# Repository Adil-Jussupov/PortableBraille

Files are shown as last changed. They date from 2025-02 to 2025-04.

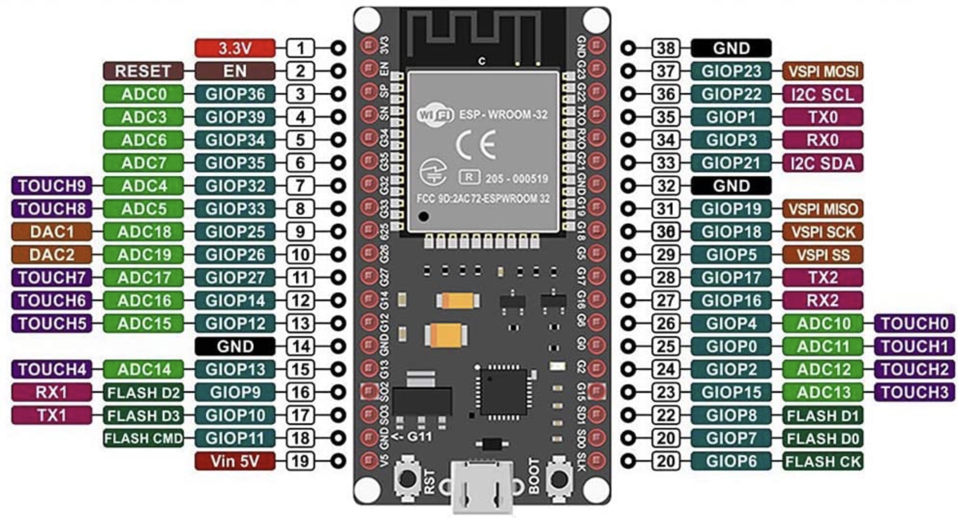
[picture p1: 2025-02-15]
DataSheets/ESP32-Pinouts.jpg

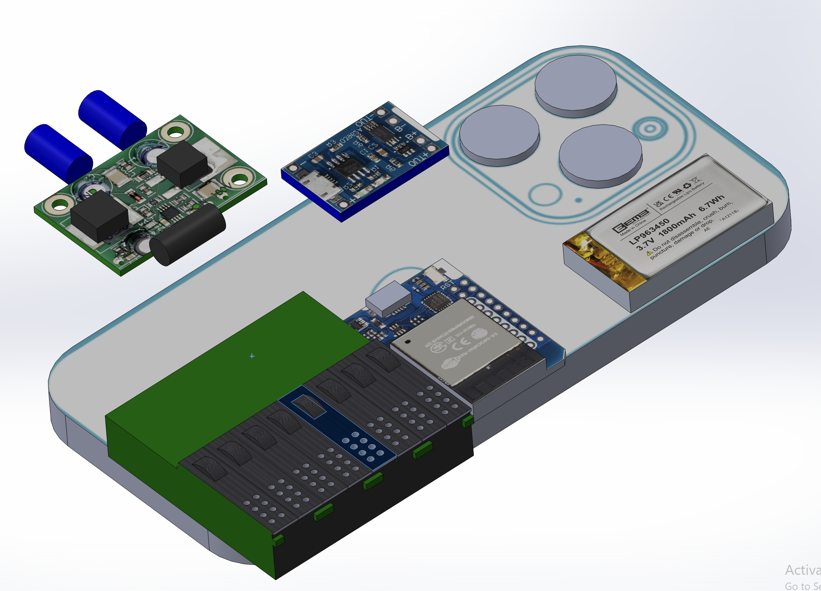
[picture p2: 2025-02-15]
Pitch_Deck/Components.png

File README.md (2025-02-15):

# PortableBraille
Educational device that encourages young visually impaired people to learn and practice Braille in order to increase chances for future employment and expand general literacy level of the community.

# Plan for designing and making the device:

1. Collected data sheets of potential components
2. Draw a schematics of the device
3. Put all components on a breadboard and run the test firmware
4. Choose electroni components to use
5. Draw several sketches of the device itself, with Phone, in hands
6. Make 3d-models of standard components
7. Asseble all standard components in general assembly
8. Model a boundry box of the device according to sketches
9. Refine the 3d-model of the device
10. Create a 3d-model of an enclosure of the divice in accordance with its 3d-Model
11. Convert parts to STL or 3dmf format
12. Slice parts and send to 3d-print
13. Put all the components inside the enclosure and if somethind doesn't fit, andjust the model and reprint.
14. Improve firmware
15. Test with user.

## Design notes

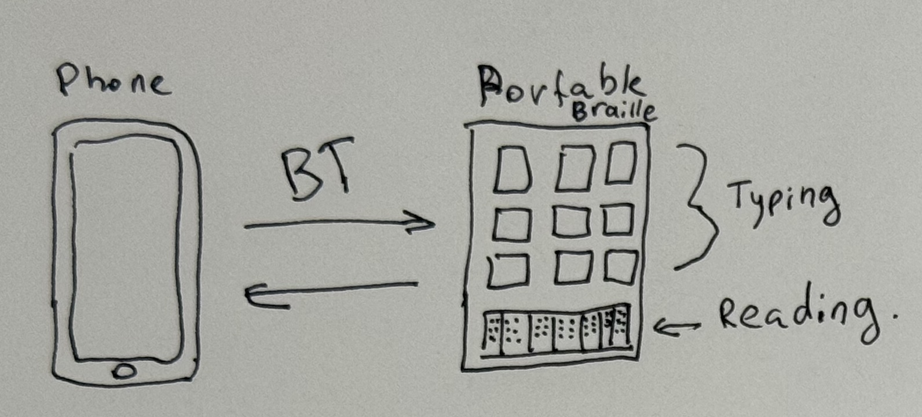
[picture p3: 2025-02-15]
Pitch_Deck/Main_schematics.jpg

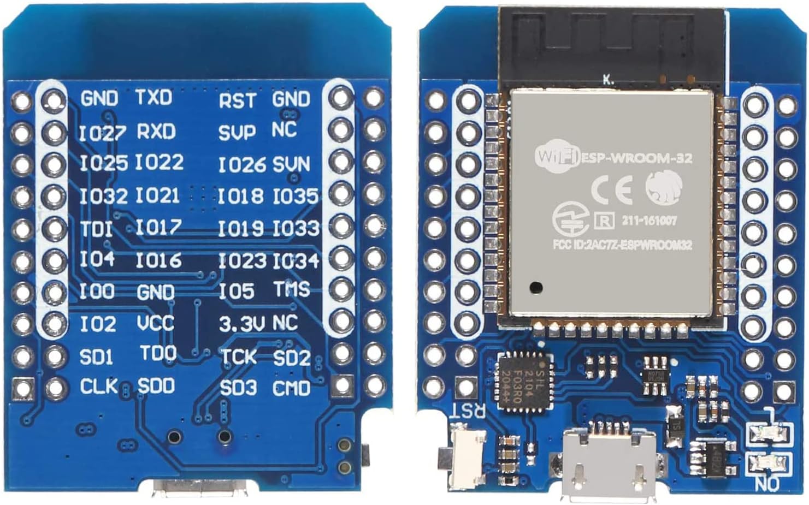
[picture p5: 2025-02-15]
DataSheets/HiLetgo_Mini_ESP-32_top_bottom.jpg

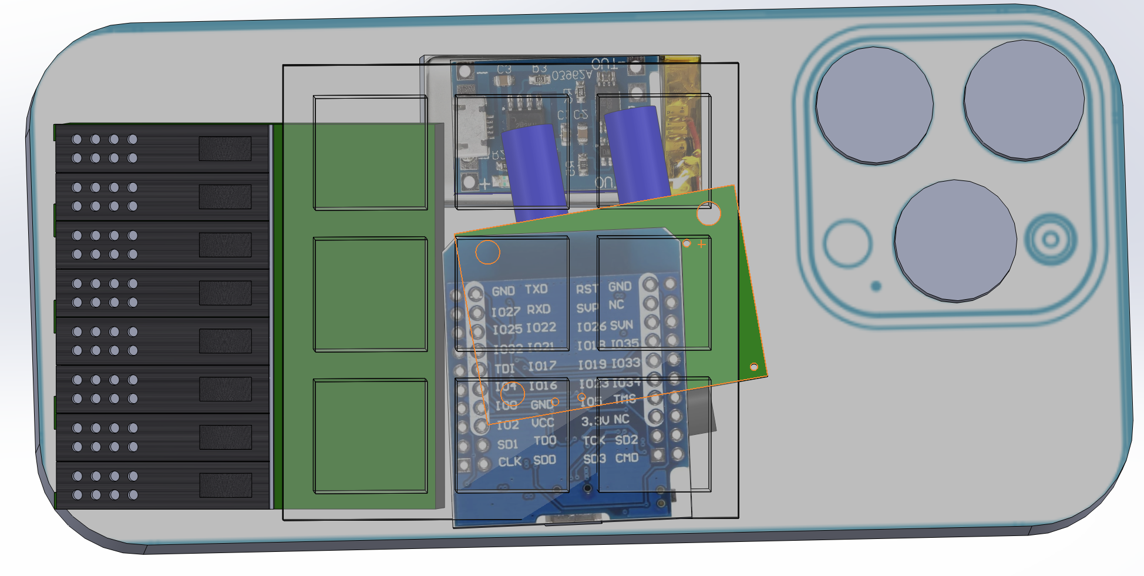
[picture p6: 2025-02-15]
Pitch_Deck/Final_arrangement.png

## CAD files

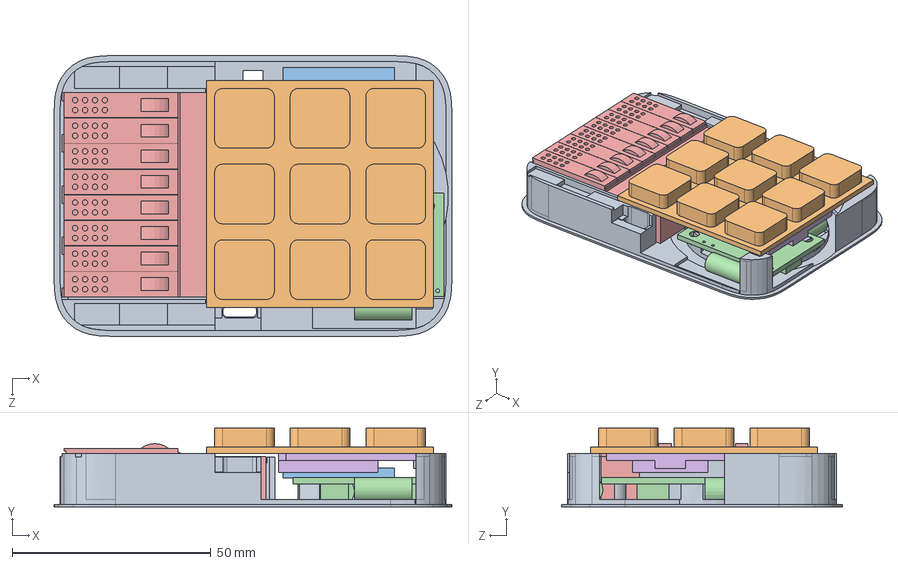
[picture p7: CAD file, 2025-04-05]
Enclosure/PB_assembly.SLDASM
100.0 x 19.8 x 70.6 mm
Mini-ESP32
Braille_flat_8
DC-DC_Metec
TP4056
Keypad
PB_Enclocure_Bottom

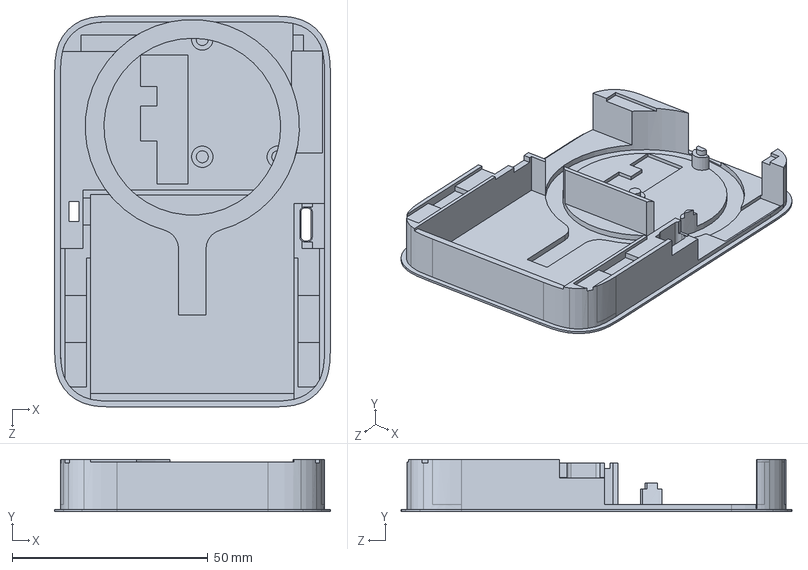
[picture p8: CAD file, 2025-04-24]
Enclosure/PB_Enclocure_Bottom.SLDPRT
70.6 x 13.4 x 100.0 mm

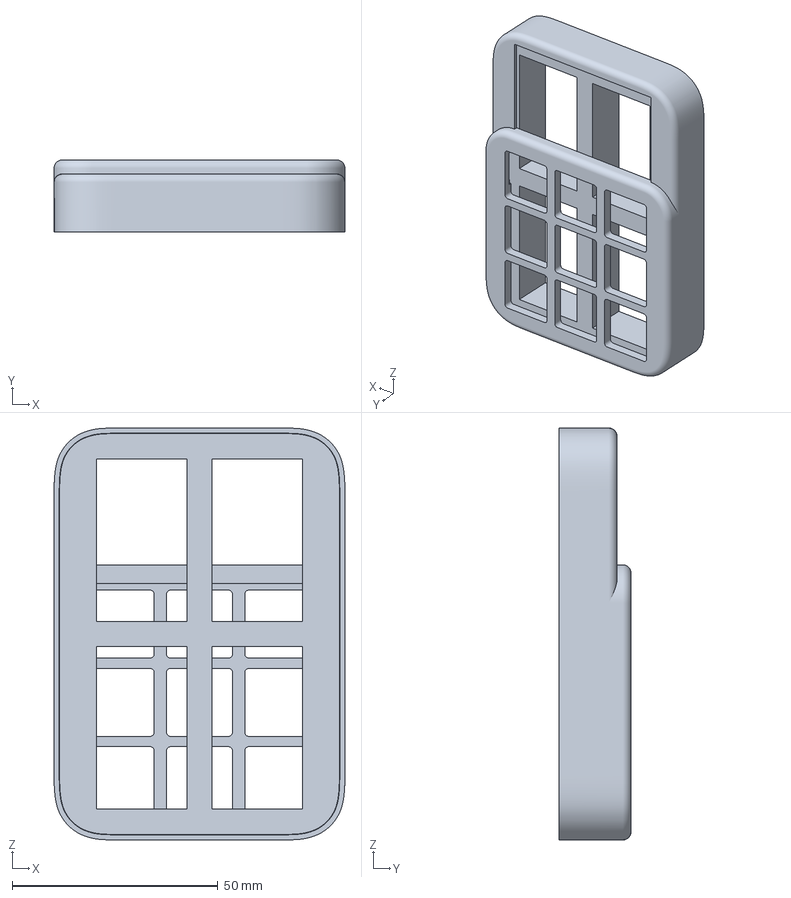
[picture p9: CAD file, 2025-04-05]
Enclosure/STL/PB_Enc_top.3MF
70.6 x 17.5 x 100.0 mm

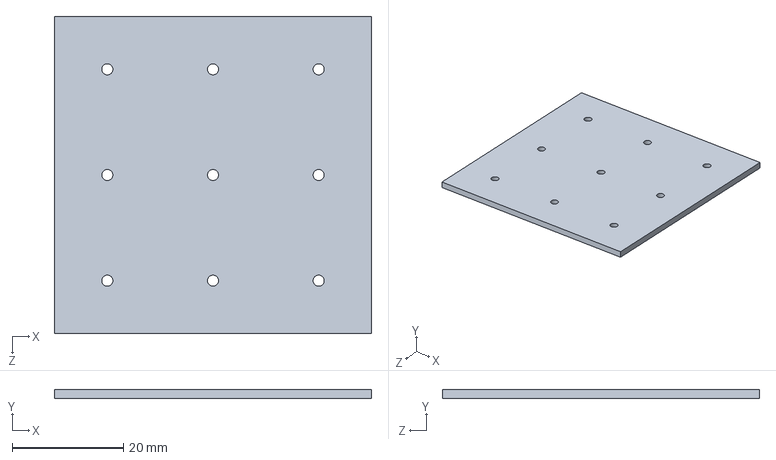
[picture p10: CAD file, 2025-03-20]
Enclosure/Part1.SLDPRT
57.0 x 1.60 x 57.0 mm

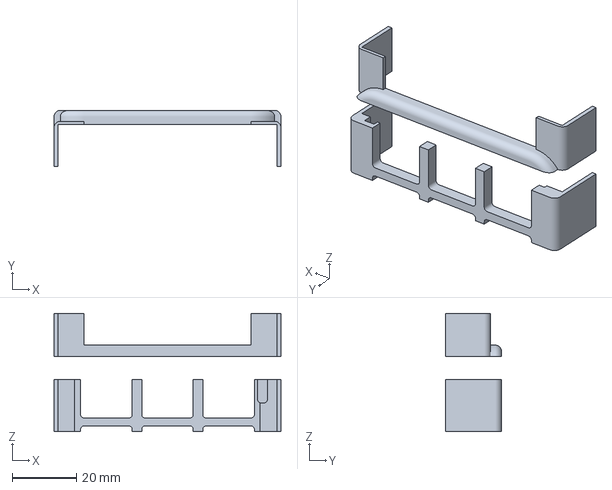
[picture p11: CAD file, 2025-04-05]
Enclosure/STL/PB_top_test.3MF
70.6 x 17.5 x 36.7 mm

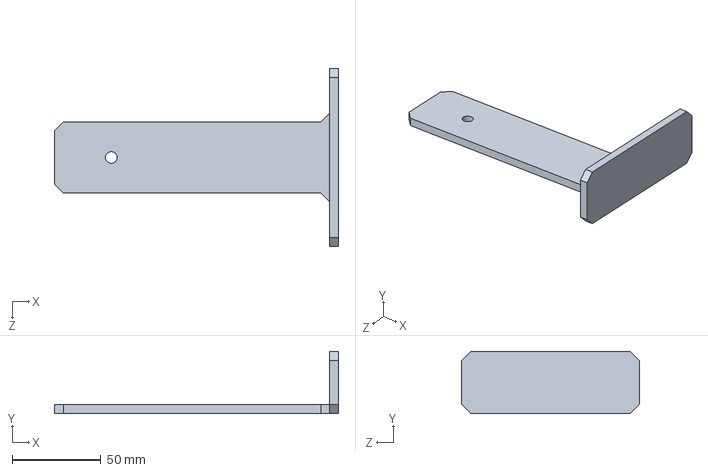
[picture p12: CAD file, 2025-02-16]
Enclosure/Camera_holder.SLDPRT
160.0 x 35.0 x 100.0 mm

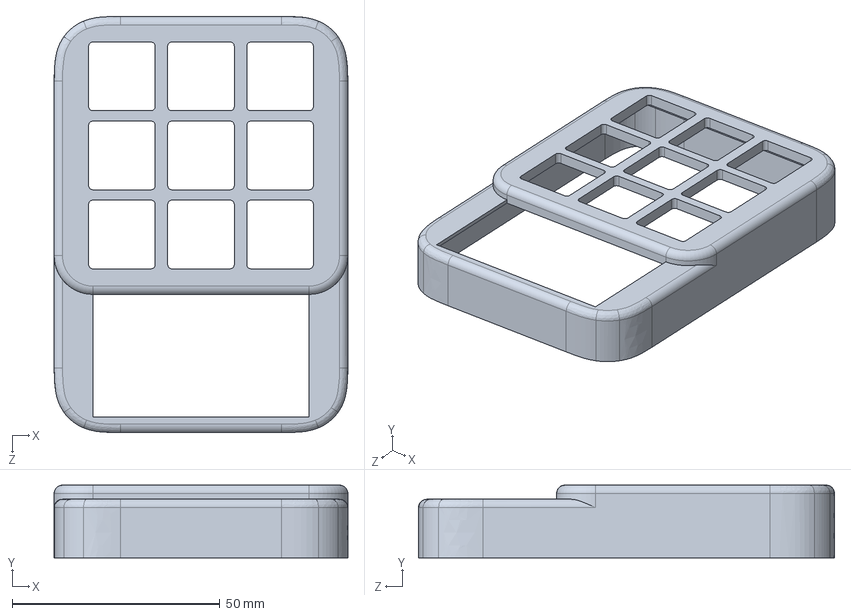
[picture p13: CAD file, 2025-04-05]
Enclosure/STL/PB_Enclocure_top.STEP
70.6 x 17.5 x 100.0 mm

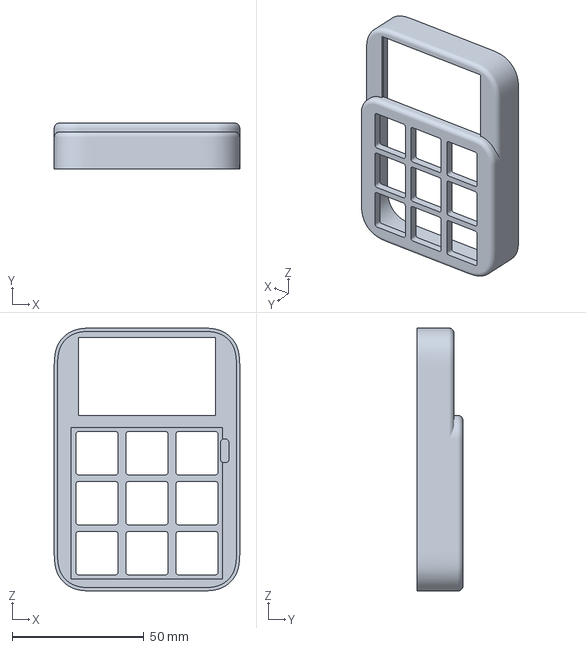
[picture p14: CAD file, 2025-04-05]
Enclosure/STL/PB_Bottom.3MF
70.6 x 17.5 x 100.0 mm

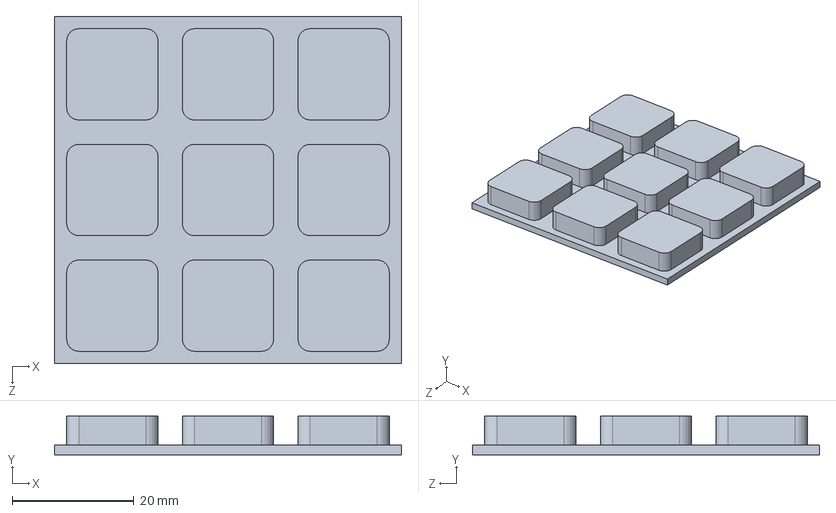
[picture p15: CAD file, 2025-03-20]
Enclosure/Standard_Parts/Keypad.SLDPRT
57.0 x 6.40 x 57.0 mm

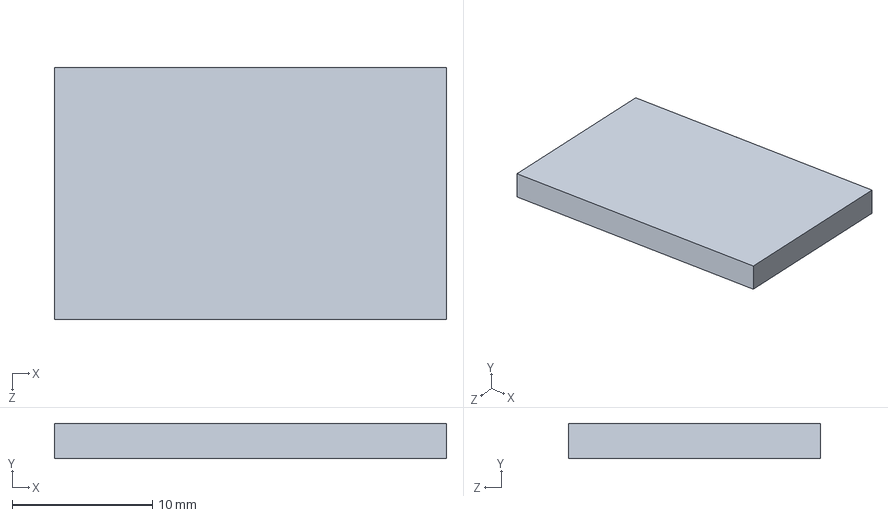
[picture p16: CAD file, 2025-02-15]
Enclosure/Standard_Parts/TP4056.SLDPRT
28.0 x 2.50 x 18.0 mm

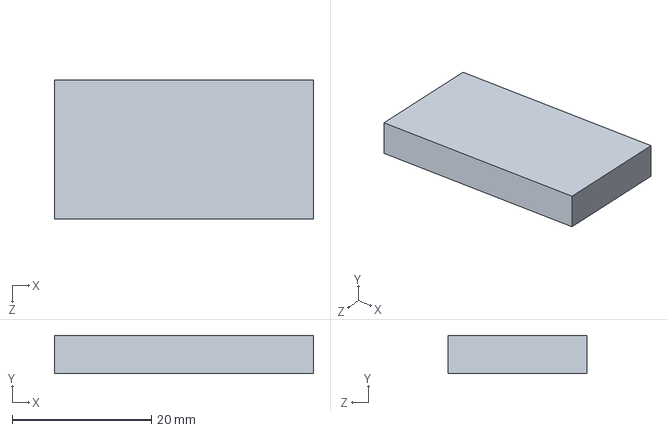
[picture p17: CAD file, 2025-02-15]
Enclosure/Standard_Parts/LiPo20x37.SLDPRT
37.2 x 5.50 x 20.0 mm

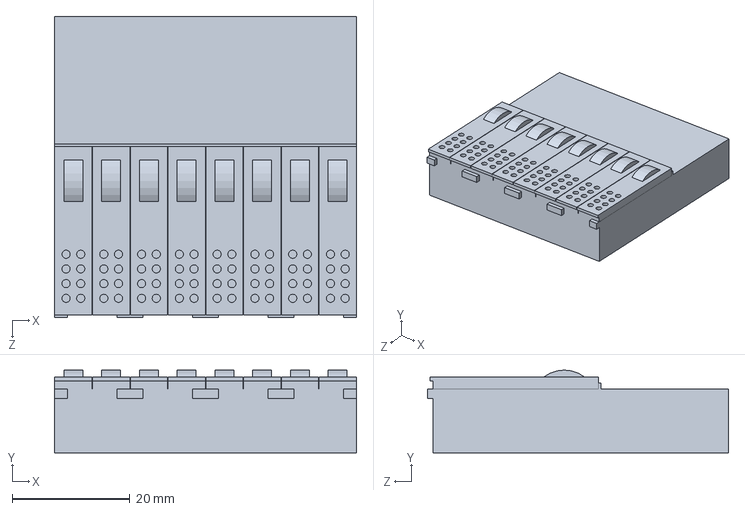
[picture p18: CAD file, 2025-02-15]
Enclosure/Standard_Parts/Braille_flat_8.SLDPRT
51.4 x 14.1 x 51.3 mm

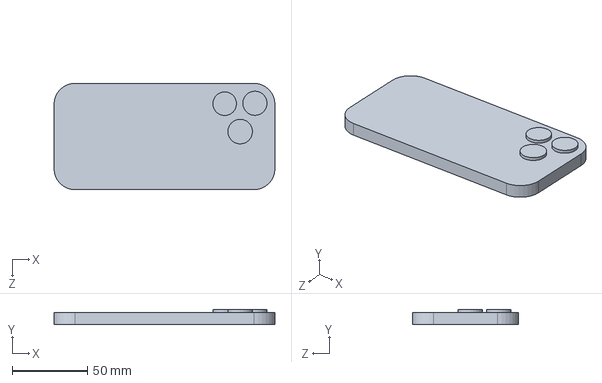
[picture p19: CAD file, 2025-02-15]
Enclosure/Standard_Parts/iPhone15Pro.SLDPRT
146.6 x 10.2 x 70.6 mm

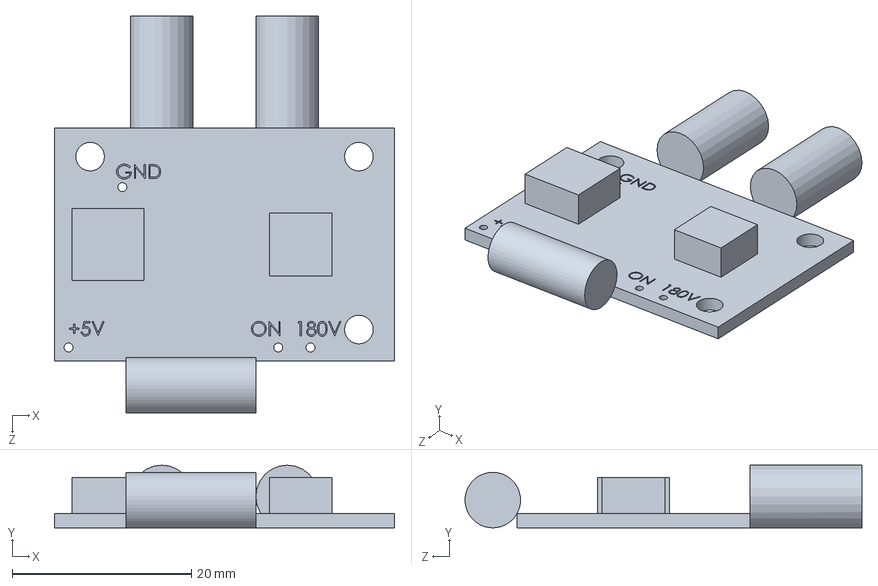
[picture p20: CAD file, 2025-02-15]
Enclosure/Standard_Parts/DC-DC_Metec.SLDPRT
38.0 x 7.00 x 44.3 mm

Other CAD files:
Enclosure/STL/PB_Enc_Bot.3MF
Enclosure/Standard_Parts/ESP32-WROOM.SLDPRT
Enclosure/Standard_Parts/Mini-ESP32.SLDPRT
Enclosure/PB_Enclocure_top.SLDPRT
Enclosure/STL/Camera_holder.3MF
Enclosure/STL/PB_Enclocure_Bottom.STL
Enclosure/STL/PB_Enclocure_top.3MF

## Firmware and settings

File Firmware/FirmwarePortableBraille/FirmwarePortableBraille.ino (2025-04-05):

// TreeHacks 2025
// PortableBraille by Adil Jussupov
// Jussupov@stanford.edu

// Define constants for pins for buttons
// mini-ESP32
#define BTN1 21
#define BTN2 19
#define BTN3 18

#define BTN4 16
#define BTN5 5
#define BTN6 23

#define BTN7 33
#define BTN8 17
#define BTN9 26

#define POWERON 4

int datainPin = 32;  //to cell, 'in' from perspective braille cell
int strobePin = 25;  //to cell
int clockPin = 27;   //to cell

unsigned int i;
float delaytime = 0.25;

#include <BleKeyboard.h>.  // library to conver device to BLE HID (Bluetooth keyboard)
#include "brailleconst.h"  // arrays for conversion to Braille

BleKeyboard bleKeyboard;

// variables for multiple buttons pressing
bool hasKeyPressed = false;      // variable for tracking and releasing pressed key
long keyPreviusTime = millis();  // temp var for time
long keyReleasTime = 10;         // time have key pressed

int number = 0;
long previousTime = millis();
long updatePeriod = 50;


#include "GyverButton.h"  // buttons library
GButton butt1(BTN1);
GButton butt2(BTN2);
GButton butt3(BTN3);
GButton butt4(BTN4);
GButton butt5(BTN5);
GButton butt6(BTN6);
GButton buttSpace(BTN7);
GButton buttBSpace(BTN8);
GButton buttEnter(BTN9);

void setup() {

  //pinMode(powerPin, OUTPUT);
  // pinMode(powerPin, OUTPUT);
  // digitalWrite(powerPin, LOW);  // controlpin for DCDC converter (low is on)
  pinMode(datainPin, OUTPUT);
  pinMode(strobePin, OUTPUT);
  pinMode(clockPin, OUTPUT);
  delay(50);

  Serial.begin(115200);
  Serial.println("Starting BLE connection");
  bleKeyboard.begin();

  pinMode(POWERON, OUTPUT);                     // pin for turning DC-DC converter on
  digitalWrite(POWERON, LOW);                   // turn off DC-DC
  // while (!bleKeyboard.isConnected()) {}  // wait untill bluetooth connected
  // Serial.println("BLE Connected");
}

void loop() {

  // tick every cycle to check buttons
  butt1.tick();
  butt2.tick();
  butt3.tick();
  butt4.tick();
  butt5.tick();
  butt6.tick();
  buttSpace.tick();
  buttBSpace.tick();
  buttEnter.tick();

  // check if button was pressed
  if (butt1.isClick()) {
    if (!number) previousTime = millis();
    if (!(number & (1 << 0))) {
      number += 1 << 0;
    }

    digitalWrite(strobePin, LOW);  // low for setting data, high for using data
    for (i = 0; i < 64; i++)       //we have five cells of eight pins, so amount is 40
    {
      digitalWrite(clockPin, LOW);  // set clock low before sending value for 1 braille pin
      if ((i % 2) == 0) {
        digitalWrite(datainPin, LOW);
      } else {
        digitalWrite(datainPin, HIGH);
      }
      delay(delaytime);              //delay must be very short
      digitalWrite(clockPin, HIGH);  //set clock low
      delay(delaytime);
    }
    digitalWrite(strobePin, HIGH);  //pattern is set and
  }
  if (butt2.isClick()) {
    if (!number) previousTime = millis();
    if (!(number & (1 << 1))) {
      number += 1 << 1;
    }

    digitalWrite(strobePin, LOW);  // low for setting, high for using data
    for (i = 0; i < 64; i++) {
      digitalWrite(clockPin, LOW);  // set clock low
      if ((i % 2) == 0)             //odd pins go down, even ones go up
      {
        digitalWrite(datainPin, HIGH);
      } else {
        digitalWrite(datainPin, LOW);
      }
      delay(delaytime);
      digitalWrite(clockPin, HIGH);
      delay(delaytime);
    }
    digitalWrite(strobePin, HIGH);
  }

  if (butt3.isClick()) {
    if (!number) previousTime = millis();
    if (!(number & (1 << 2))) {
      number += 1 << 2;
    }
    digitalWrite(strobePin, LOW);  // low for setting data, high for using data
    for (i = 0; i < 64; i++)       //we have five cells of eight pins, so amount is 40
    {
      digitalWrite(clockPin, LOW);  // set clock low before sending value for 1 braille pin
      if ((i % 2) == 0) {
        digitalWrite(datainPin, LOW);
      } else {
        digitalWrite(datainPin, HIGH);
      }
      delay(delaytime);              //delay must be very short
      digitalWrite(clockPin, HIGH);  //set clock low
      delay(delaytime);
    }
    digitalWrite(strobePin, HIGH);  //pattern is set and
  }

  if (butt4.isClick()) {
    if (!number) previousTime = millis();
    if (!(number & (1 << 3))) {
      number += 1 << 3;
    }

    digitalWrite(strobePin, LOW);  // low for setting, high for using data
    for (i = 0; i < 64; i++) {
      digitalWrite(clockPin, LOW);  // set clock low
      if ((i % 2) == 0)             //odd pins go down, even ones go up
      {
        digitalWrite(datainPin, HIGH);
      } else {
        digitalWrite(datainPin, LOW);
      }
      delay(delaytime);
      digitalWrite(clockPin, HIGH);
      delay(delaytime);
    }
    digitalWrite(strobePin, HIGH);
  }

  if (butt5.isClick()) {
    if (!number) previousTime = millis();
    if (!(number & (1 << 4))) {
      number += 1 << 4;
    }

    digitalWrite(strobePin, LOW);  // low for setting data, high for using data
    for (i = 0; i < 64; i++)       //we have five cells of eight pins, so amount is 40
    {
      digitalWrite(clockPin, LOW);  // set clock low before sending value for 1 braille pin
      if ((i % 2) == 0) {
        digitalWrite(datainPin, LOW);
      } else {
        digitalWrite(datainPin, HIGH);
      }
      delay(delaytime);              //delay must be very short
      digitalWrite(clockPin, HIGH);  //set clock low
      delay(delaytime);
    }
    digitalWrite(strobePin, HIGH);  //pattern is set and
  }

  if (butt6.isClick()) {
    if (!number) previousTime = millis();
    if (!(number & (1 << 5))) {
      number += 1 << 5;
    }


    digitalWrite(strobePin, LOW);  // low for setting, high for using data
    for (i = 0; i < 64; i++) {
      digitalWrite(clockPin, LOW);  // set clock low
      if ((i % 2) == 0)             //odd pins go down, even ones go up
      {
        digitalWrite(datainPin, HIGH);
      } else {
        digitalWrite(datainPin, LOW);
      }
      delay(delaytime);
      digitalWrite(clockPin, HIGH);
      delay(delaytime);
    }
    digitalWrite(strobePin, HIGH);
  }

  if (buttSpace.isClick()) {
    bleKeyboard.print(" ");
    Serial.print(" ");  // WhiteSpace
    hasKeyPressed = true;
  }
  if (buttEnter.isClick()) {
    bleKeyboard.write(KEY_RETURN);
    Serial.print("\n");
    hasKeyPressed = true;
  }
  if (buttBSpace.isClick()) {
    bleKeyboard.print(" ");
    Serial.print("BackSpace");
    hasKeyPressed = true;
  }

  if (previousTime < (millis() - updatePeriod)) {
    if (number) {
      if (number >= B1000000) {
        // Serial.println("Send text");
      } else {
        // Serial.print(number, BIN);
        // Serial.print(" - ");
        bleKeyboard.print((char)asciiCodes[number]);
        Serial.print((char)asciiCodes[number]);
        // Serial.println(";");
        hasKeyPressed = true;
      }
      number = 0;
      previousTime = millis();
    }
  }

  if (hasKeyPressed) {
    if ((millis() - keyPreviusTime) >= keyReleasTime) {
      hasKeyPressed = false;
    }
  }
  // ///////////////////////////////////////////////////////////





  // ///////////////////////////////////////////////////////////
}

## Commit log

2025-02-15 Datasheets and dimensions
    Collected datasheets and dimensions of microcontrollers modules: ESP32 Wroom, Mini, NRF52840, and Braille line
2025-02-15 Created 3d-models of standard parts
    Created models of:
    - ESP32-Wroom
    - Mini_ESP-32
    [ESP32-WROOM.SLDPRT, Mini-ESP32.SLDPRT]
2025-02-15 Add model of standard parts
    Crated models of:
    iPhone15pro,
    Braille _line8,
    Li-Po battery,
    DC-DC Step-up boost convertor
    Charger module TP4056
    [Braille_flat_8.SLDPRT, DC-DC_Metec.SLDPRT, LiPo20x37.SLDPRT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]
2025-02-15 Designed the main schematics
    Main schematics
    Block diagram of units
    Created assembly and added all components
    [PB_assembly.SLDASM]
2025-02-15 Keypad added
    [Keypad.SLDPRT, PB_assembly.SLDASM]
2025-02-15 Design 3d models of enclosure
    3d-models of enclosure parts: top and bottom
    Assembled device
    [Keypad.SLDPRT, PB_Enclocure_Bottom.SLDPRT, PB_Enclocure_top.SLDPRT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]
2025-02-16 Minor changes to 3d-Models
    3d-models were updated after printing prototypes
    Added time-laps of printing parts
    [PB_Enclocure_Bottom.3MF, PB_Enclocure_Bottom.SLDPRT, PB_Enclocure_Bottom.STL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]
2025-02-16 test of 9 buttons keypad
    added 9 buttons in firmware
    [Camera_holder.3MF, Camera_holder.SLDPRT]
2025-02-16 Multi button press added
    Added support of pressing multiple buttons simultaniously
2025-02-16 Video pitch
2025-03-20 Version with PCB - wrong PCB sizes
    [Keypad.SLDPRT, PB_Enclocure_Bottom.3MF, PB_Enclocure_Bottom.SLDPRT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]
2025-04-05 Updates for Apr-4
    [PB_Bottom.3MF, PB_Enc_Bot.3MF, PB_Enc_top.3MF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]
2025-04-24 Recent updates
    [PB_Enc_Bot.3MF, PB_Enclocure_Bottom.SLDPRT]
